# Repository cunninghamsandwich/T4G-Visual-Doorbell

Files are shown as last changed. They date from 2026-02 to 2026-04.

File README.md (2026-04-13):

# Visual Doorbell

An open-source visual alert doorbell system designed to support isolated seniors and individuals with partial or full hearing loss. This project augments an off-the-shelf wireless doorbell with an acknowledgement button and a responsive e-paper display to facilitate simple, accessible communication with visitors.

The device is comprised of off-the-shelf electronics and 3D printed parts. The total cost of materials is about $40 USD (excluding component shipping fees and 3D printed parts).

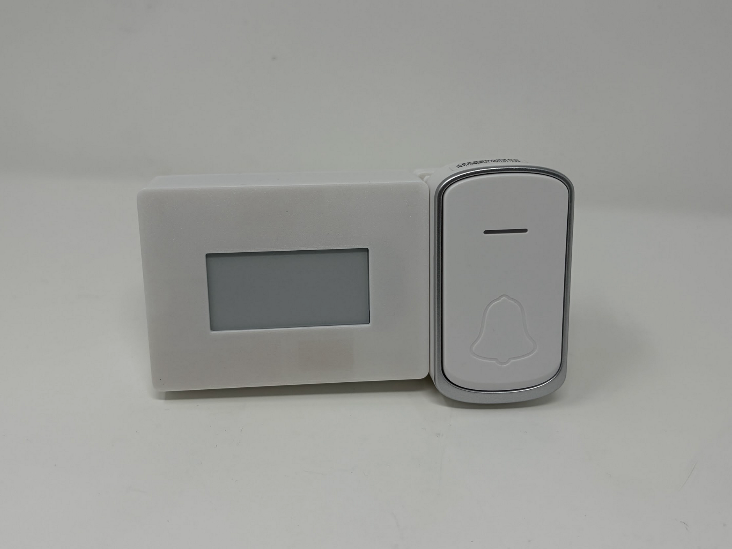
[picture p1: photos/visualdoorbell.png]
Picture of Visual Doorbell.


## About the Project

**Who is this for?**

Isolated individuals living in public rental flats or alone, especially those who:

- Have partial or full hearing loss.
- Move slowly due to age or mobility impairments.
- Rely on community support.

**What does it do?**

1. Provides a clear visual indication inside the home when the doorbell is pressed.
2. Features an exterior e-paper display that informs visitors (e.g., displaying "I'm coming" when acknowledged by the resident).

## Features

- **Low-Power Operation:** The ESP32-C6 MCU remains in deep-sleep mode during idle periods and is woken by a hardware interrupt only when triggered, maximizing battery life.
- **No Wi-Fi/Internet Required:** Operates entirely independently of cloud services, utilizing local wired connections and 433 MHz RF communication for rock-solid reliability.
- **Accessible Notifications:** High-contrast e-paper displays and visual light indicators make it highly suitable for the hearing impaired.
- **Simple Interaction:** Uses a minimal two-button interface (one for the visitor, one for the user) to eliminate steep learning curves.

## System Architecture

The system is divided into two functional subsystems:

1. **Inform User (Indoor):** When a visitor presses the outdoor doorbell, an indoor indicator light activates.
2. **Inform Visitor (Outdoor):** If the user is home and presses their indoor acknowledge button, a 433 MHz wireless signal is transmitted to the outdoor RF module. The ESP32-C6 wakes up and updates the E-Paper display to let the visitor know the user is on their way to the door.

## How to Obtain the Device

### 1. Do-it-Yourself (DIY) or Do-it-Together (DIT)

This is an open-source assistive technology, so anyone is free to build it. All of the files and instructions required to build the device are contained within this repository. Refer to the Maker Guide below.

### 2. Get Involved: Requests & Volunteering

- Need this device? If you or someone you know could benefit from the Visual Doorbell, please send us an email at [contactus@engineeringgood.org](mailto:contactus@engineeringgood.org). We also invite you to share your journey with us! Tell us your stories about the device and feedback help us make our assistive tech even better!

- Want to help? We are always looking for volunteers to help build these devices for the community. If you have the skills and want to contribute, please contact us via email at [contactus@engineeringgood.org](mailto:contactus@engineeringgood.org).

## Build Instructions

### 1. Read through the Product Manual

The [Product Manual](/documentation/VisualDoorbell_Product_Manual_v1.pdf) contains all the necessary information to build this device, including tool lists, assembly instructions, and testing.

### 2. Order the Off-The-Shelf Components

The [Bill of Materials](/documentation/BOM_v1.csv) lists all of the parts and components required to build the Template Device.

### 3. Assemble the Template Device

Reference the Assembly Guide section of the [Product Manual](/documentation/VisualDoorbell_Product_Manual_v1.pdf) for the tools and steps required to build each portion.

## How to improve this Device

As open source assistive technology, you are welcomed and encouraged to improve upon the design.

## Files

### Documentation

| Document | Version | Link |
|---|---|---|
| Product Manual | 1.0 | [VisualDoorbell_Product_Manual_v1](/documentation/VisualDoorbell_Product_Manual_v1.pdf) |
| Bill of Materials | 1.0 | [BOM_v1](/documentation/BOM_v1.csv) |

## Open Source Attribution

This documentation template was created by Makers Making Change / Neil Squire Society and is used under a CC BY-SA 4.0 license. It is available at the following link: [MMC OpenAt Template](https://github.com/makersmakingchange/OpenAT-Template)

## Copyright & License

Copyright 2026 Engineering Good.

This repository contains open source hardware:

- Everything needed or used to design, make, test, or prepare the Visual Doorbell is licensed under the [Apache 2.0 License](https://www.apache.org/licenses/LICENSE-2.0).
- Accompanying material such as instruction manuals, videos, and other copyrightable works that are useful but not necessary to design, make, test, or prepare the Visual Doorbell are published under a [Creative Commons Attribution-ShareAlike 4.0 license (CC BY-SA 4.0)](https://creativecommons.org/licenses/by-sa/4.0/).

Source Location: <https://github.com/Engineering-Good/T4G-Visual-Doorbell>

----

<!-- ABOUT EG START -->
## About Engineering Good

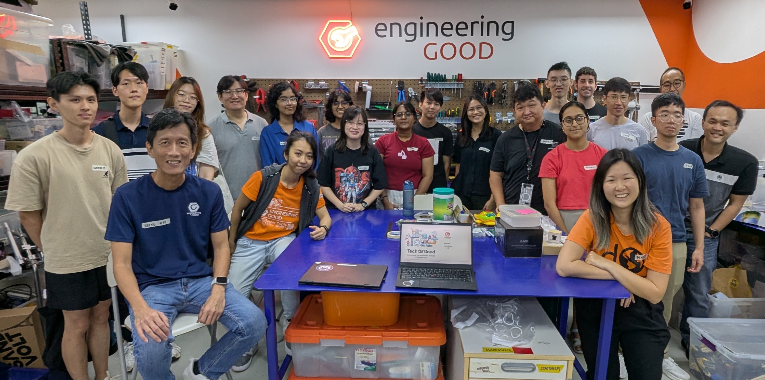
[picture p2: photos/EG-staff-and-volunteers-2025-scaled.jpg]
Picture of EG staff and volunteers.


- Website: [https://www.engineeringgood.org](https://www.engineeringgood.org)
- GitHub: [Engineering-Good](https://github.com/Engineering-Good)
- Instagram: [@engineeringgood](https://www.instagram.com/engineeringgood/)
- Facebook: [engineeringgood](https://www.facebook.com/engineeringgood.org/)
- LinkedIn: [engineeringgood](https://www.linkedin.com/company/engineeringgood/?originalSubdomain=sg)
- Thingiverse: [engineeringgood](https://www.thingiverse.com/engineeringgood/designs)
- Printables: [@engineeringg_4351657](https://www.printables.com/@engineeringg_4351657)

### Contact Us

For technical or non-techical questions, to get involved, or to share your experience we encourage you to

- Visit [our website](https://www.engineeringgood.org/)
- Contact us via our [contact us form](https://www.engineeringgood.org/contact-faq/)
- Email us at [contactus@engineeringgood.org](mailto:contactus@engineeringgood.org)
<!-- ABOUT EG END -->

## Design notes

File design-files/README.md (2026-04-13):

# Design Files

This folder contains the design files for the 3D printed components:

[stl-files](design-files/stl-files):  This contains .stl files for use directly in 3D printing software.

[step-files](design-files/step-files):  This contains .step files for use in CAD software.

These files were created using OnShape. You can view and edit the original design here: (<https://cad.onshape.com/documents/337ad5c4e913baa748541b1a/w/32a3bb0dc3194d3076de666c/e/9b7dc48c14887d3fe6e58874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>)

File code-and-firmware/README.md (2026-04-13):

This folder contains the code or firmware for the device:

- [visualdoorbell.ino](code-and-firmware/visualdoorbell.ino) - main code for XIAO ESP32-C6
- [driver.h](code-and-firmware/driver.h) - driver definition for epaper display (see [https://wiki.seeedstudio.com/xiao_eink_expansion_board_v2/#software-preparation](https://wiki.seeedstudio.com/xiao_eink_expansion_board_v2/#software-preparation))

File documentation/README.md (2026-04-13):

# Documentation

This folder contains the latest documentation files for the device.

- [BOM_v1.csv](documentation/BOM_v1.csv) - Bill of Materials for the device
- [VisualDoorbell_Product_Manual_v1.pdf](documentation/VisualDoorbell_Product_Manual_v1.pdf) - Product manual for the device

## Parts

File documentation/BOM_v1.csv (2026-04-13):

Item | Product Link | Supplier | Price | Quantity
ESP32-C6 module | https://www.seeedstudio.com/Seeed-Studio-XIAO-ESP32C6-p-5884.html | Seeed Studio | $5.20 USD | 1
ePaper Driver board | https://www.seeedstudio.com/ePaper-breakout-Board-for-XIAO-V2-p-6374.html | Seeed Studio | $4.90 USD | 1
2.13" ePaper Display | https://www.seeedstudio.com/2-13-Monochrome-ePaper-Display-with-122x250-Pixels-p-5778.html | Seeed Studio | $6.50 USD | 1
LiPo Battery | https://shopee.sg/Rechargeable-Battery-602020-Battery-180mAh-Li-Polymer-3.7V-For-Replacement-Bluetooth-Device-Toys-Watch-Beauty-Equipment-i.212115178.28254519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 | Shopee | $6.43 SGD | 1
3D Printed Casing | N/A | N/A | $0 | 1
Wireless Doorbell | https://shopee.sg/SMATRUL-Wireless-Doorbells-Door-Bell-Ring-62-Chimes-110db-Battery-Door-Bell-Ring-Alarm-Button-Transmitter-Calling-Home-bell-IP44-Waterproof-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 | Shopee | $10.19 SGD | 1
Wireless receiver Button | https://shopee.sg/product/1107145475/24708021201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 | Shopee | $3.58 SGD | 1
433MHz Superheterodyne Module | https://shopee.sg/product/1107145475/25661343069 | Shopee | $3.05 SGD | 1
Push Button | https://shopee.sg/KENTON-Push-Button-Switch-20Pcs-Lot-ON-OFF-Keys-Mini-Micro-Momentary-Switch-Accessories-Tactile-Plush-Button-i.455466453.23148962418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 | Shopee | $1.98 SGD | 1
Male to Female Jumper Wires | https://shopee.sg/ENGLAB-10cm-20cm-30cm-40Pins-Jumper-Wire-DuPont-Wire-(Male-Female-M-M-F-F)-For-DIY-Breadboard-Arduino-Raspberry-Pi-Multiple-Options-40Pins-i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 | Shopee | $1.64 SGD | 1

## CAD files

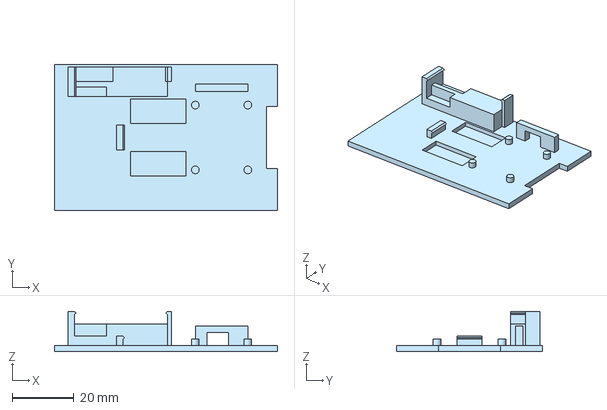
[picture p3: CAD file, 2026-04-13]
design-files/step-files/ScreenFaceInsert.step
72.2 x 47.2 x 13.0 mm

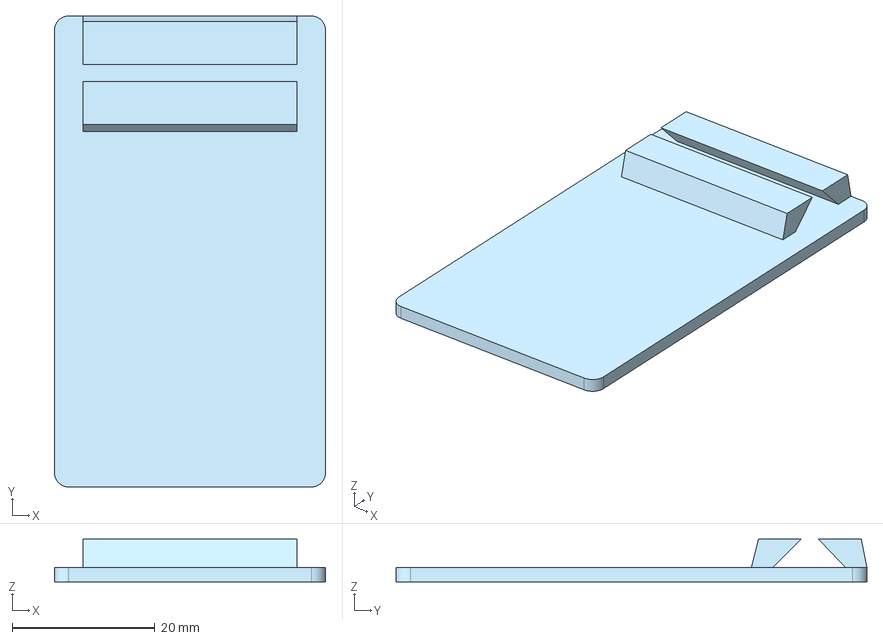
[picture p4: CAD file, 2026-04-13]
design-files/step-files/ButtonFlap.step
38.0 x 66.0 x 6.00 mm

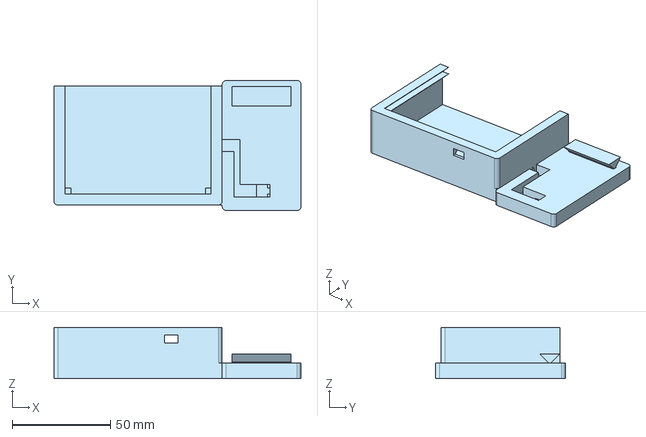
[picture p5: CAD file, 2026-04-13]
design-files/step-files/EnclosureBase.step
125.4 x 66.0 x 26.0 mm

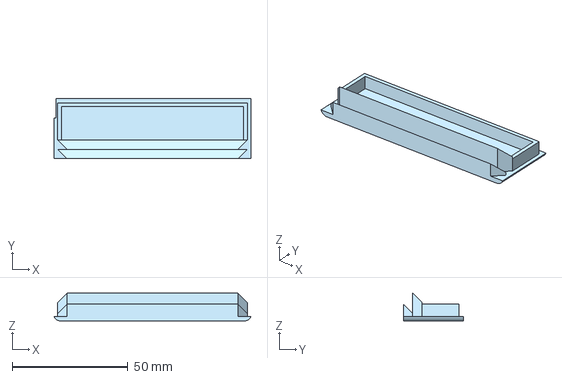
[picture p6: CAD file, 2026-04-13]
design-files/step-files/EnclosureLid.step
85.1 x 26.0 x 12.0 mm

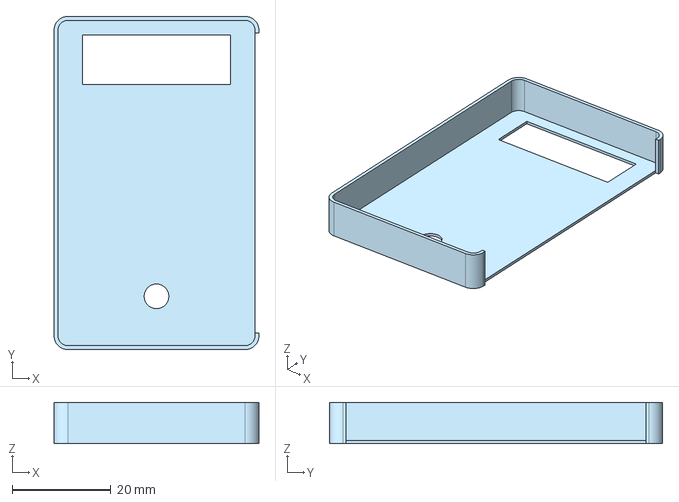
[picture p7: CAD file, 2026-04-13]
design-files/step-files/ButtonCover.step
41.6 x 67.6 x 8.40 mm

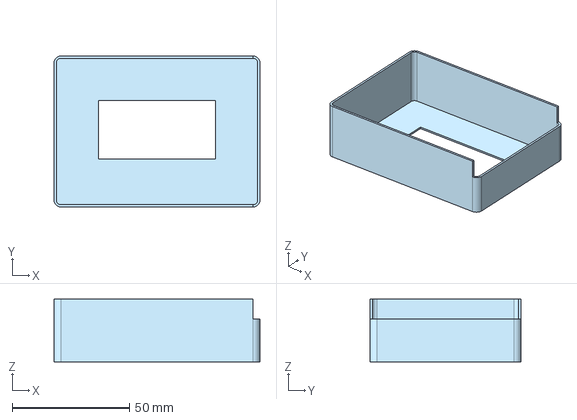
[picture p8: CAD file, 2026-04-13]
design-files/step-files/EnclosureCover.step
87.8 x 64.4 x 26.8 mm

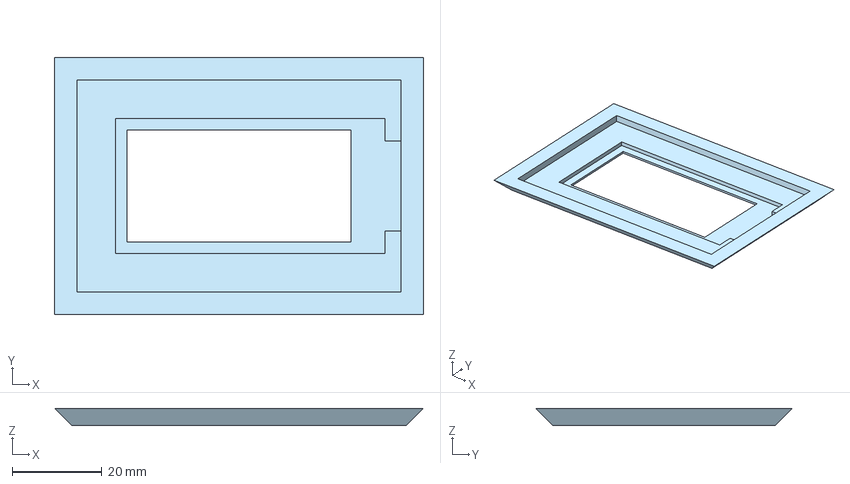
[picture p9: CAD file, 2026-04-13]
design-files/step-files/ScreenFace.step
82.2 x 57.2 x 3.80 mm

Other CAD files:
design-files/stl-files/ButtonCover.stl
design-files/stl-files/ButtonFlap.stl
design-files/stl-files/EnclosureBase.stl
design-files/stl-files/EnclosureCover.stl
design-files/stl-files/EnclosureLid.stl
design-files/stl-files/ScreenFace.stl
design-files/stl-files/ScreenFaceInsert.stl

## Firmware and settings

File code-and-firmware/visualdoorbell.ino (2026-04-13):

/*
 * Copyright 2026 Engineering Good
 *
 * Licensed under the Apache License, Version 2.0 (the "License");
 * you may not use this file except in compliance with the License.
 * You may obtain a copy of the License at
 *
 *     https://www.apache.org/licenses/LICENSE-2.0
 *
 * Unless required by applicable law or agreed to in writing, software
 * distributed under the License is distributed on an "AS IS" BASIS,
 * WITHOUT WARRANTIES OR CONDITIONS OF ANY KIND, either express or implied.
 * See the License for the specific language governing permissions and
 * limitations under the License.
 */

#include "driver.h"        // from https://seeed-studio.github.io/Seeed_GFX/
#include "driver/rtc_io.h" // from https://github.com/espressif/esp-idf
#include "esp_sleep.h"     // from https://github.com/espressif/esp-idf
#include <RCSwitch.h>      // from https://github.com/sui77/rc-switch
#include <TFT_eSPI.h>      // from https://github.com/Seeed-Studio/Seeed_GFX

// ==================== SLEEP SETTINGS =================
// The specific pad on the back of the XIAO ESP32C6 is GPIO4
#define WAKEUP_GPIO GPIO_NUM_4 // Only RTC IO are allowed - GPIO0-7
// How long to stay awake looking for signal (in milliseconds)
#define RF_LISTEN_TIMEOUT 60000
RTC_DATA_ATTR int bootCount = 0; // Configure a boot counter
unsigned long wakeStartTime = 0;
// ==============================================================

// ==================== SCREEN ROTATION SETTING =================
// 0 = Portrait (0°)
// 1 = Landscape (90°)
// 2 = Portrait Inverted (180°)
// 3 = Landscape Inverted (270°)
// CHANGE THIS NUMBER if the screen is still not facing the right way
#define DISPLAY_ROTATION 3
// ==============================================================

// ==================== RF SETTINGS =============================
#define RECEIVE_PIN D4        // Using GPIO22 (D4) for RF receiver
#define BUTTON_CODE_1 4137576 // Your specific RF code (Button 2)
// ==============================================================

EPaper epaper;
RCSwitch mySwitch = RCSwitch();
// unsigned long lastTriggerTime = 0;
const unsigned long DISPLAY_DURATION = 10000; // 10 seconds
// bool messageDisplayed = false;

// ===========================================================
//                    SLEEP FUNCTIONS
// ===========================================================

void enterDeepSleep() {
  Serial.println("[SYSTEM] Preparing for Deep Sleep...");
  // 1. Put the display controller to sleep to save power and protect screen
  epaper.sleep();
  // 2. Configure Wakeup Pin
  // We use INPUT_PULLUP assuming the button connects the pin to GND
  pinMode(WAKEUP_GPIO, INPUT_PULLUP);
  // 3. Enable Wakeup
  // 1ULL << WAKEUP_GPIO creates the bitmask
  // ESP_GPIO_WAKEUP_GPIO_LOW means wake up when button is pressed (connected to
  // GND)
  esp_deep_sleep_enable_gpio_wakeup(1ULL << WAKEUP_GPIO,
                                    ESP_GPIO_WAKEUP_GPIO_LOW);
  Serial.println("[SYSTEM] Goodnight.");
  Serial.flush(); // Ensure serial message sends before processor cuts off
  esp_deep_sleep_start();
}

void print_wakeup_reason() {
  esp_sleep_wakeup_cause_t wakeup_reason;
  wakeup_reason = esp_sleep_get_wakeup_cause();
  switch (wakeup_reason) {
  case ESP_SLEEP_WAKEUP_EXT0:
    Serial.println("Wakeup caused by external signal using RTC_IO");
    break;
  case ESP_SLEEP_WAKEUP_EXT1:
    Serial.println("Wakeup caused by external signal using RTC_CNTL");
    break;
  case ESP_SLEEP_WAKEUP_TIMER:
    Serial.println("Wakeup caused by timer");
    break;
  case ESP_SLEEP_WAKEUP_TOUCHPAD:
    Serial.println("Wakeup caused by touchpad");
    break;
  case ESP_SLEEP_WAKEUP_ULP:
    Serial.println("Wakeup caused by ULP program");
    break;
  default:
    Serial.printf("Wakeup was not caused by deep sleep: %d\n", wakeup_reason);
    break;
  }
}

// ===========================================================
//                    DISPLAY FUNCTIONS
// ===========================================================

void setScreenWhite() {
  Serial.println("[DISPLAY] Cleaning screen...");
  epaper.fillRect(
      0, 0, epaper.width(), epaper.height(),
      TFT_WHITE); // Erase the screen by filling it with a white rectangle
  epaper.update();
  Serial.println("[DISPLAY] Screen cleared.");
}

void showMessage() {
  Serial.println("[DISPLAY] RF Signal Received -> Showing Message");
  setScreenWhite();
  // epaper.fillScreen(TFT_WHITE); // Clear screen to White
  epaper.setTextColor(TFT_BLACK, TFT_WHITE); // Set Text color, Background color
  epaper.setTextSize(3);                     // Set Text size
  epaper.setTextDatum(MC_DATUM);             // Set middle Center alignment
  epaper.drawString(
      "I'm coming", epaper.width() / 2,
      epaper.height() /
          2); // Draw the string in the exact center of the current rotation
  epaper.update();
  Serial.println("[DISPLAY] Message displayed.");
}

// ===========================================================
//                           SETUP
// ===========================================================
void setup() {
  Serial.begin(115200);
  delay(1000);
  ++bootCount;

  Serial.println("\n\n========== Xiao ESP32-C6 SYSTEM START ==========");
  Serial.println("Boot number: " + String(bootCount));
  print_wakeup_reason();

  Serial.println("Board: Xiao ESP32-C6");
  Serial.println("Display: TFT_eSPI");
  Serial.println("RF: 433MHz Receiver");

  // 1. Initialize Display
  Serial.println("[DISPLAY] Initializing Display...");
  epaper.begin(); // Initialize epaper display
  epaper.setRotation(DISPLAY_ROTATION);
  // But don't draw anything yet! We don't want the screen flashing/refreshing
  // just because we woke up to listen.

  /* (this is the old screen refresh code)
  epaper.fillRect(0,0,epaper.width(),epaper.height(),TFT_WHITE); // Erase the
  screen by filling it with a white rectangle
  // Test the display with a simple pattern
  epaper.setTextColor(TFT_BLACK, TFT_WHITE);
  epaper.setTextSize(1);
  epaper.drawString("System Ready", 10, 10);
  epaper.update();
  */
  Serial.println("[DISPLAY] Display initialized.");

  // 2. Initialize RF
  Serial.print("[RF] Enabling Receiver on Pin: D");
  Serial.println(RECEIVE_PIN);
  mySwitch.enableReceive(
      digitalPinToInterrupt(RECEIVE_PIN)); // Initialize RCSwitch

  // 3. Start Timer
  wakeStartTime = millis();
  Serial.println("[SYSTEM] Setup Complete. Waiting 60s for RF signal...");
}

// ===========================================================
//                           LOOP
// ===========================================================
void loop() {
  // -------------------------------------------------
  // CONDITION 1: RF Signal Received
  // -------------------------------------------------
  if (mySwitch.available()) {
    unsigned long value = mySwitch.getReceivedValue();
    if (value != 0) {
      Serial.print("[RF] Signal Detected - Code: ");
      Serial.println(value);
      Serial.print("[RF] Bit length: ");
      Serial.println(mySwitch.getReceivedBitlength());
      if (value == BUTTON_CODE_1) {
        Serial.println("[RF] Valid Code! Updating Display...");
        showMessage();
        Serial.println("[SYSTEM] Waiting 10 seconds...");
        delay(DISPLAY_DURATION);
        setScreenWhite();
        enterDeepSleep();
      }
    }
    mySwitch.resetAvailable();
  }

  // -------------------------------------------------
  // CONDITION 2: 60 Second Timeout Reached
  // -------------------------------------------------
  if (millis() - wakeStartTime >= RF_LISTEN_TIMEOUT) {
    Serial.println("[TIMEOUT] No signal received in 60 seconds.");
    enterDeepSleep();
  }

  // Small delay to prevent watchdog issues
  delay(10);
}

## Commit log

2026-03-14 Add initial visual doorbell firmware for XIAO ESP32-C6 and update README with file descriptions.
2026-04-13 Add design files and documentation while consolidating project licensing and cleaning up directory structure
    [BOM_v1.csv, ButtonCover.step, ButtonCover.stl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]
2026-04-13 docs: update documentation links and references to reflect new product manual and BOM filenames
